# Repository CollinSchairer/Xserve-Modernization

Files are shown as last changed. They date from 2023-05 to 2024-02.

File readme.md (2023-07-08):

Making Apple's beautiful but whacky servers of old useable in 2023.

This project aims to adapt modern ATX computer hardware into the 1U Xserve chassis while maintaining as much of the original design and hardware as possible.
As I work through this project, less and less of this original hardware seems to be useable, but I'm trying my best.

The main components of this modification are a revised front panel I/O and indication board, hard drive caddy modifications, a revised and modernized 
SATA (Maybe SAS?) backplane, and a revised back panel to fit an ATX motherboard I/O cutout and Flex ATX power supply.
# Xserve-Modernization

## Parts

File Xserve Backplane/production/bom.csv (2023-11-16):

Designator | Footprint | Quantity | Value | LCSC Part #
C1 | 0603 | 1 | 10uF
C10 | CP_EIA-7343-15_Kemet-W_Pad2.25x2.55mm_HandSolder | 1 | DNP
C11, C12, C13, C14, C7 | 1210 | 5 | 47uF
C15 | 1210 | 1 | 47 uF
C16, C17 | 0603 | 2 | 10 uF
C2 | 0603 | 1 | 0.1uF
C3 | 0603 | 1 | 2400 pF
C4, C5 | 0603 | 2 | 0.1 uF
C6 | 0603 | 1 | 150 pF
C8 | 0603 | 1 | 22 uF
C9 | CP_EIA-7343-15_Kemet-W_Pad2.25x2.55mm_HandSolder | 1 | 68 uF
CN1, CN2, CN3 | 0678008025_SATA_Conn | 3 | 0678008025_SATA_Conn
D1 | 0805 | 1 | LED_Small
H1 | Slide Mount Hole | 1 | MountingHole_Pad
J1, J7, J8 | 10124274-001TRLF | 3 | ~
J2 | 6_pin_PCI_PWR | 1 | Conn_02x03_Odd_Even
J3 | TE_1888019-2 | 1 | 1888019-2
JP1 | SolderJumper-3_P1.3mm_Bridged2Bar12_Pad1.0x1.5mm_NumberLabels | 1 | Jumper_3_Bridged12
L1 | L_12x12mm_H8mm | 1 | 15 uH
Q1, Q2, Q3, Q4, Q5, Q6 | SOT-23 | 6 | Q_NMOS_DGS
R1 | 0603 | 1 | 19.1 k
R10, R3 | 0603 | 2 | 10k
R2 | 0603 | 1 | 52.3k
R4, R5, R6, R7 | 0603 | 4 | 500 k
R8 | 0603 | 1 | 100 k
R9 | 0603 | 1 | 500 k
TP1 | TheColonelCu | 1 | TestPoint_Probe
U1 | Texas_HTSOP-8-1EP_3.9x4.9mm_P1.27mm_EP2.95x4.9mm_Mask2.4x3.1mm_ThermalVias | 1 | BD9E302EFJ-E2

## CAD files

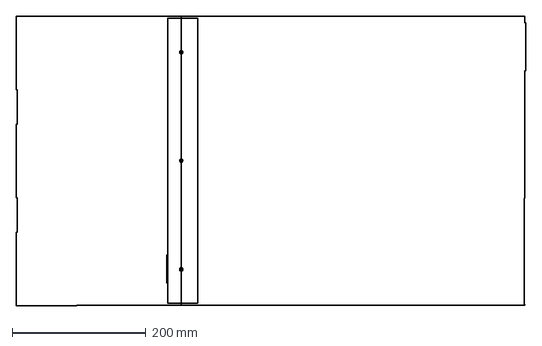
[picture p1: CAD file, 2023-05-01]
Xserve Backplane/backplane_outline.dxf
762.0 x 433.5 mm

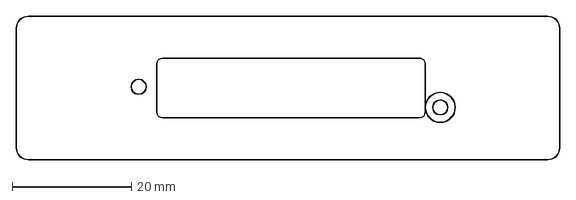
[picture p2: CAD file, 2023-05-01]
Xserve Caddy/Board Outline.dxf
91.0 x 24.0 mm

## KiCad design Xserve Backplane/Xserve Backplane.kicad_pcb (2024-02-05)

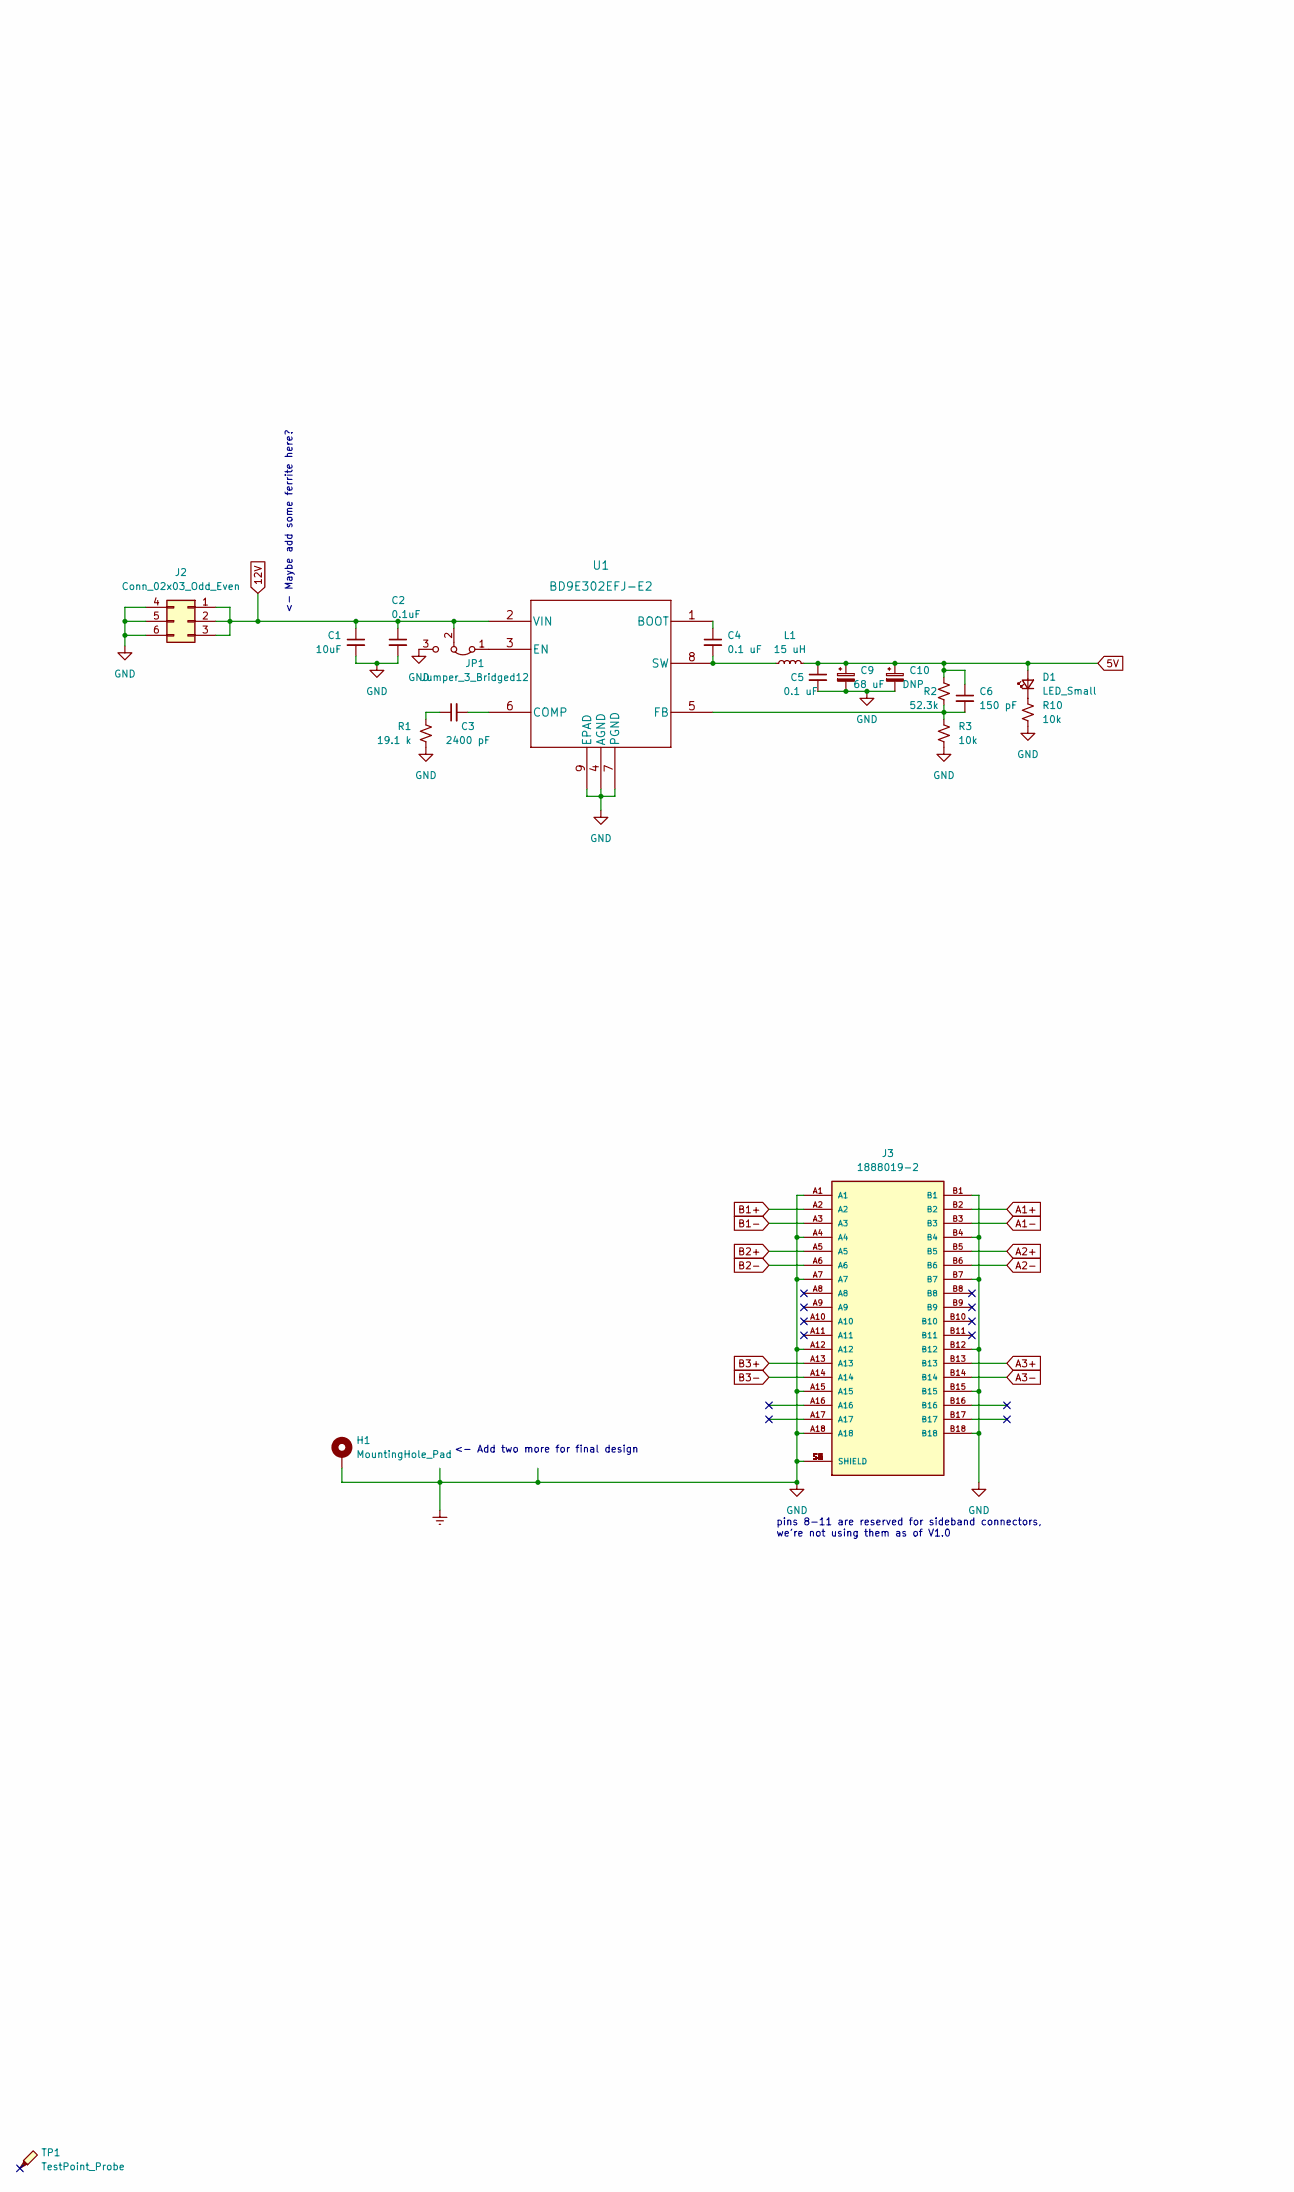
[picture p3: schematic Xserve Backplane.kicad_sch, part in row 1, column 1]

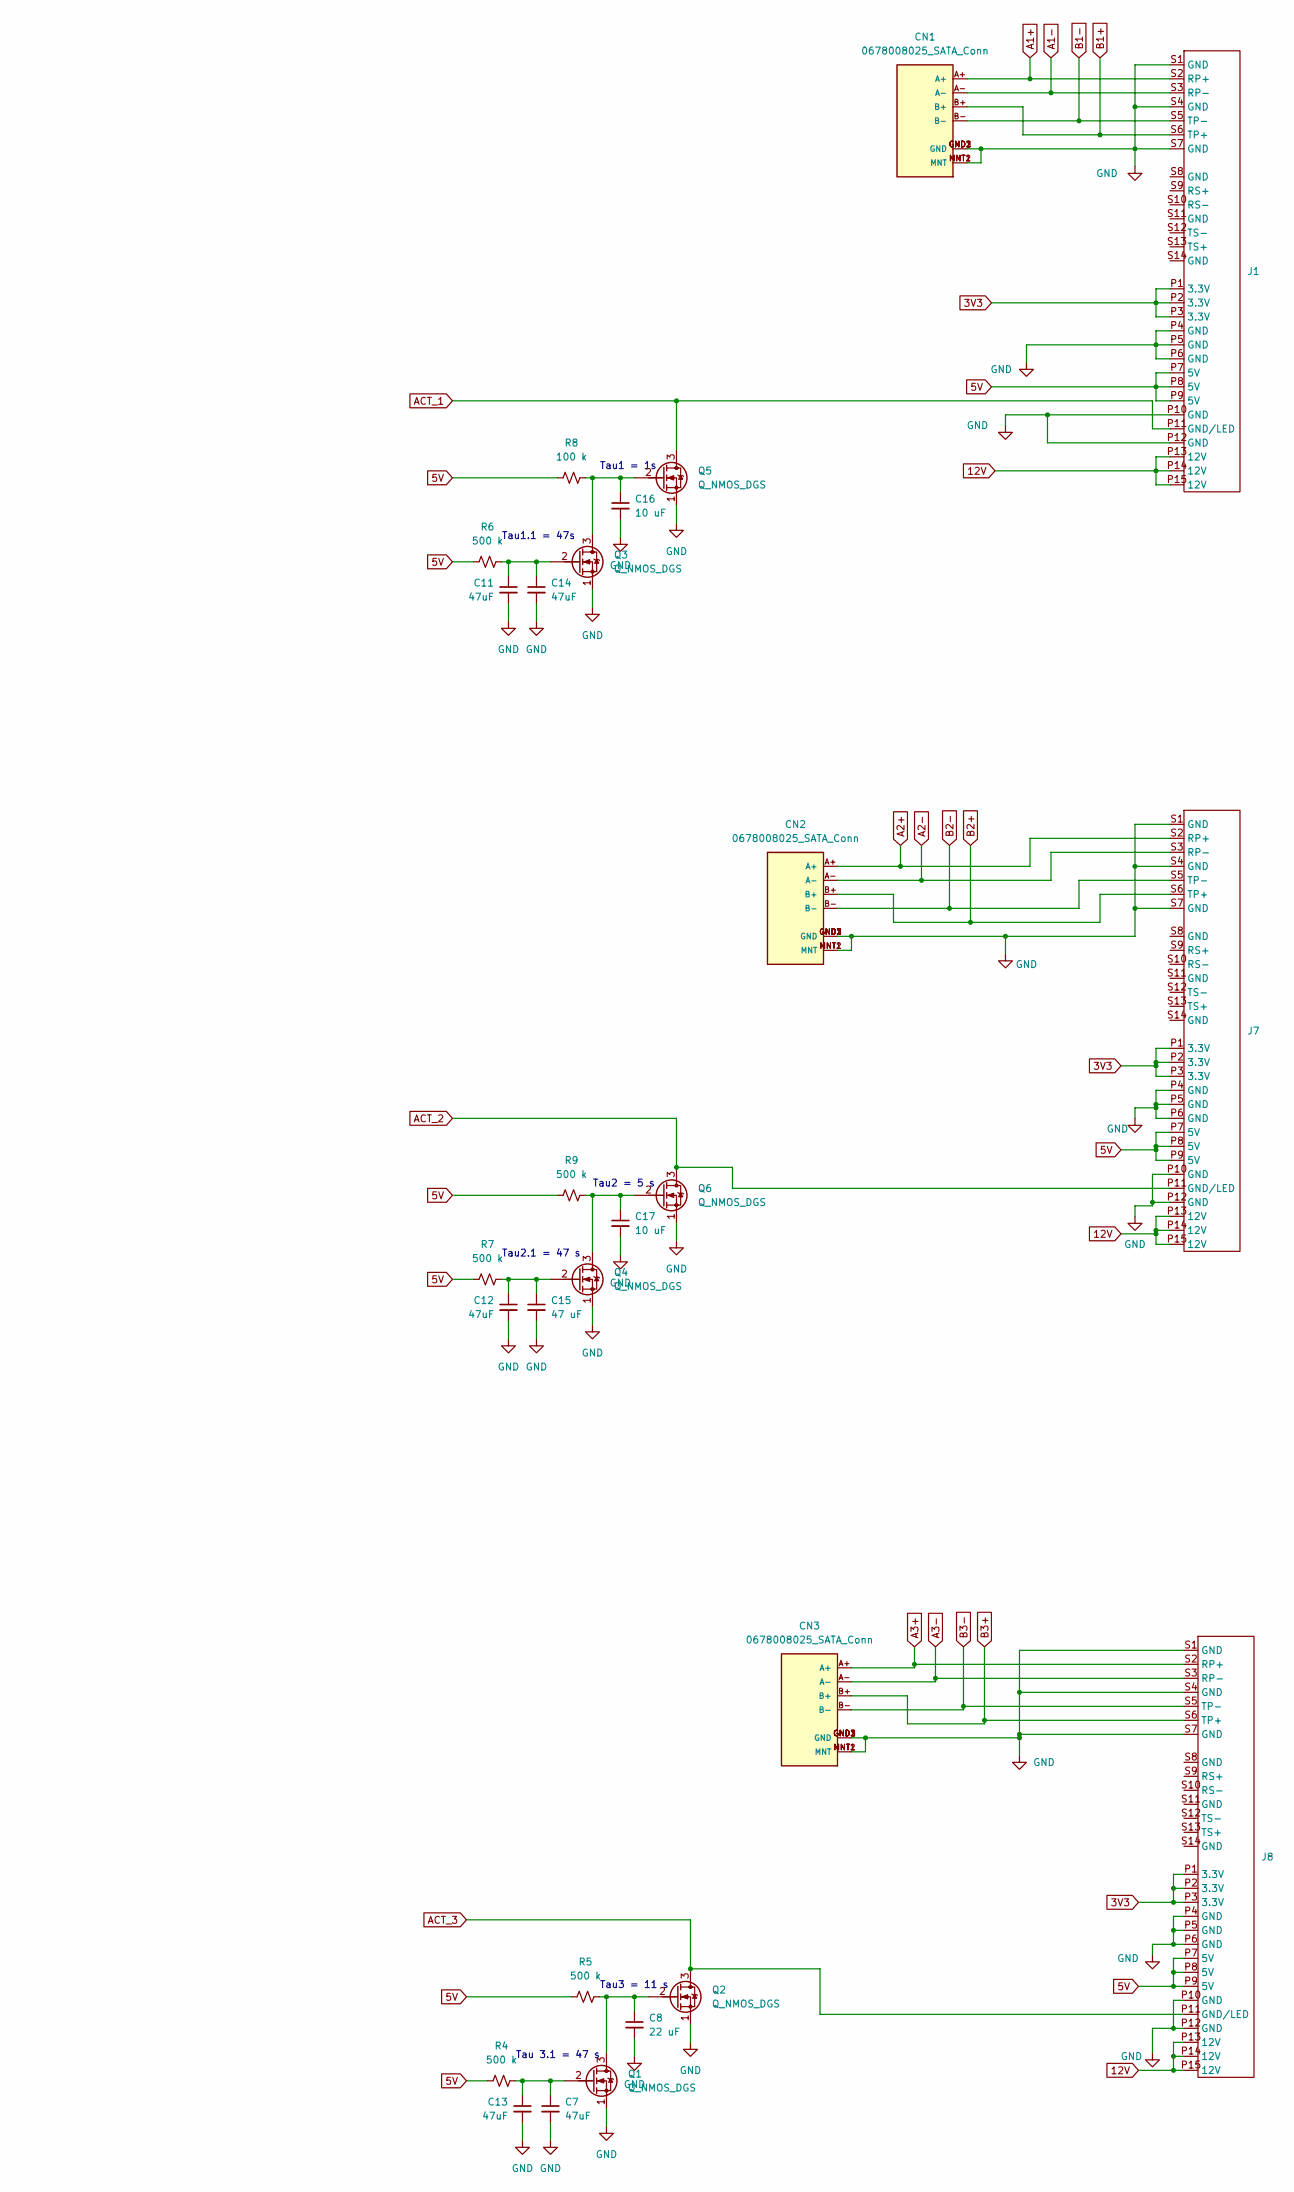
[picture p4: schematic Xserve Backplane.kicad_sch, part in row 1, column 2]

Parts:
C1: 10uF; C_0603_1608Metric_Pad1.08x0.95mm_HandSolder
C2: 0.1uF; C_0603_1608Metric_Pad1.08x0.95mm_HandSolder
C3: 2400 pF; C_0603_1608Metric_Pad1.08x0.95mm_HandSolder
C4, C5: 0.1 uF; C_0603_1608Metric_Pad1.08x0.95mm_HandSolder
C6: 150 pF; C_0603_1608Metric_Pad1.08x0.95mm_HandSolder
C7, C11, C12, C13, C14: 47uF; C_1210_3225Metric_Pad1.33x2.70mm_HandSolder
C8: 22 uF; C_0603_1608Metric_Pad1.08x0.95mm_HandSolder
C9: 68 uF; CP_EIA-7343-15_Kemet-W_Pad2.25x2.55mm_HandSolder
C10: DNP; CP_EIA-7343-15_Kemet-W_Pad2.25x2.55mm_HandSolder
C15: 47 uF; C_1210_3225Metric_Pad1.33x2.70mm_HandSolder
C16, C17: 10 uF; C_0603_1608Metric_Pad1.08x0.95mm_HandSolder
CN1, CN2, CN3: 0678008025_SATA_Conn
D1: LED_Small; LED_0805_2012Metric_Pad1.15x1.40mm_HandSolder
H1: MountingHole_Pad; Slide Mount Hole
J1, J7, J8: 10124274-001TRLF
J2: Conn_02x03_Odd_Even; 6_pin_PCI_PWR
J3: 1888019-2; TE_1888019-2
JP1: Jumper_3_Bridged12; SolderJumper-3_P1.3mm_Bridged2Bar12_Pad1.0x1.5mm_NumberLabe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
L1: 15 uH; L_12x12mm_H8mm
Q1, Q2, Q3, Q4, Q5, Q6: Q_NMOS_DGS; SOT-23
R1: 19.1 k; R_0603_1608Metric_Pad0.98x0.95mm_HandSolder
R2: 52.3k; R_0603_1608Metric_Pad0.98x0.95mm_HandSolder
R3, R10: 10k; R_0603_1608Metric_Pad0.98x0.95mm_HandSolder
R4, R5, R6, R7, R9: 500 k; R_0603_1608Metric_Pad0.98x0.95mm_HandSolder
R8: 100 k; R_0603_1608Metric_Pad0.98x0.95mm_HandSolder
TP1: TestPoint_Probe; TheColonelCu
U1: BD9E302EFJ-E2; Texas_HTSOP-8-1EP_3.9x4.9mm_P1.27mm_EP2.95x4.9mm_Mask2.4x3.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

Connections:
3V3: J1.P1 (3.3V), J1.P2 (3.3V), J1.P3 (3.3V), J7.P1 (3.3V), J7.P2 (3.3V), J7.P3 (3.3V), J8.P1 (3.3V), J8.P2 (3.3V), J8.P3 (3.3V)
5V: C5.1, C6.1, C9.1, C10.1, D1.2 (A), J1.P7 (5V), J1.P8 (5V), J1.P9 (5V), J7.P7 (5V), J7.P8 (5V), J7.P9 (5V), J8.P7 (5V), J8.P8 (5V), J8.P9 (5V), L1.2, R2.1, R4.1, R5.1, R6.1, R7.1, R8.1, R9.1
12V: C1.1, C2.1, J1.P13 (12V), J1.P14 (12V), J1.P15 (12V), J2.1, J2.2, J2.3, J7.P13 (12V), J7.P14 (12V), J7.P15 (12V), J8.P13 (12V), J8.P14 (12V), J8.P15 (12V), JP1.2 (C), U1.2 (VIN)
A1+: CN1.A+, J1.S2 (RP+), J3.B2
A1-: CN1.A-, J1.S3 (RP-), J3.B3
A2+: CN2.A+, J3.B5, J7.S2 (RP+)
A2-: CN2.A-, J3.B6, J7.S3 (RP-)
A3+: CN3.A+, J3.B13, J8.S2 (RP+)
A3-: CN3.A-, J3.B14, J8.S3 (RP-)
ACT_1: J1.P11 (GND/LED), Q5.3 (D)
ACT_2: J7.P11 (GND/LED), Q6.3 (D)
ACT_3: J8.P11 (GND/LED), Q2.3 (D)
B1+: CN1.B+, J1.S6 (TP+), J3.A2
B1-: CN1.B-, J1.S5 (TP-), J3.A3
B2+: CN2.B+, J3.A5, J7.S6 (TP+)
B2-: CN2.B-, J3.A6, J7.S5 (TP-)
B3+: CN3.B+, J3.A13, J8.S6 (TP+)
B3-: CN3.B-, J3.A14, J8.S5 (TP-)
Earth: C1.2, C2.2, C5.2, C7.2, C8.2, C9.2, C10.2, C11.2, C12.2, C13.2, C14.2, C15.2, C16.2, C17.2, CN1.GND1 (GND), CN1.GND2 (GND), CN1.GND3 (GND), CN1.MNT1 (MNT), CN1.MNT2 (MNT), CN2.GND1 (GND), CN2.GND2 (GND), CN2.GND3 (GND), CN2.MNT1 (MNT), CN2.MNT2 (MNT), CN3.GND1 (GND), CN3.GND2 (GND), CN3.GND3 (GND), CN3.MNT1 (MNT), CN3.MNT2 (MNT), H1.1, J1.P4 (GND), J1.P5 (GND), J1.P6 (GND), J1.P10 (GND), J1.P12 (GND), J1.S1 (GND), J1.S4 (GND), J1.S7 (GND), J2.4, J2.5, J2.6, J3.A1, J3.A4, J3.A7, J3.A12, J3.A15, J3.A18, J3.B1, J3.B4, J3.B7, J3.B12, J3.B15, J3.B18, J3.S1 (SHIELD), J3.S2 (SHIELD), J3.S3 (SHIELD), J3.S4 (SHIELD), J3.S5 (SHIELD), J3.S6 (SHIELD), J7.P4 (GND), J7.P5 (GND), J7.P6 (GND), J7.P10 (GND), J7.P12 (GND), J7.S1 (GND), J7.S4 (GND), J7.S7 (GND), J8.P4 (GND), J8.P5 (GND), J8.P6 (GND), J8.P10 (GND), J8.P12 (GND), J8.S1 (GND), J8.S4 (GND), J8.S7 (GND), JP1.3 (B), Q1.1 (S), Q2.1 (S), Q3.1 (S), Q4.1 (S), Q5.1 (S), Q6.1 (S), R1.2, R3.2, R10.2, U1.4 (AGND), U1.7 (PGND), U1.9 (EPAD)
unnamed: C3.1, R1.1
unnamed: D1.1 (K), R10.1
unnamed: JP1.1 (A), U1.3 (EN)
unnamed: C8.1, Q1.3 (D), Q2.2 (G), R5.2
unnamed: C7.1, C13.1, Q1.2 (G), R4.2
unnamed: C16.1, Q3.3 (D), Q5.2 (G), R8.2
unnamed: C11.1, C14.1, Q3.2 (G), R6.2
unnamed: C17.1, Q4.3 (D), Q6.2 (G), R9.2
unnamed: C12.1, C15.1, Q4.2 (G), R7.2
unnamed: C4.1, U1.1 (BOOT)
unnamed: C3.2, U1.6 (COMP)
unnamed: C6.2, R2.2, R3.1, U1.5 (FB)
unnamed: C4.2, L1.1, U1.8 (SW)

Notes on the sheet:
Tau2.1 = 47 s
pins 8-11 are reserved for sideband connectors, we're not using them as of V1.0
<- Add two more for final design
Tau2 = 5 s
<- Maybe add some ferrite here?
Tau1 = 1s
Tau1.1 = 47s
Tau3 = 11 s
Tau 3.1 = 47 s

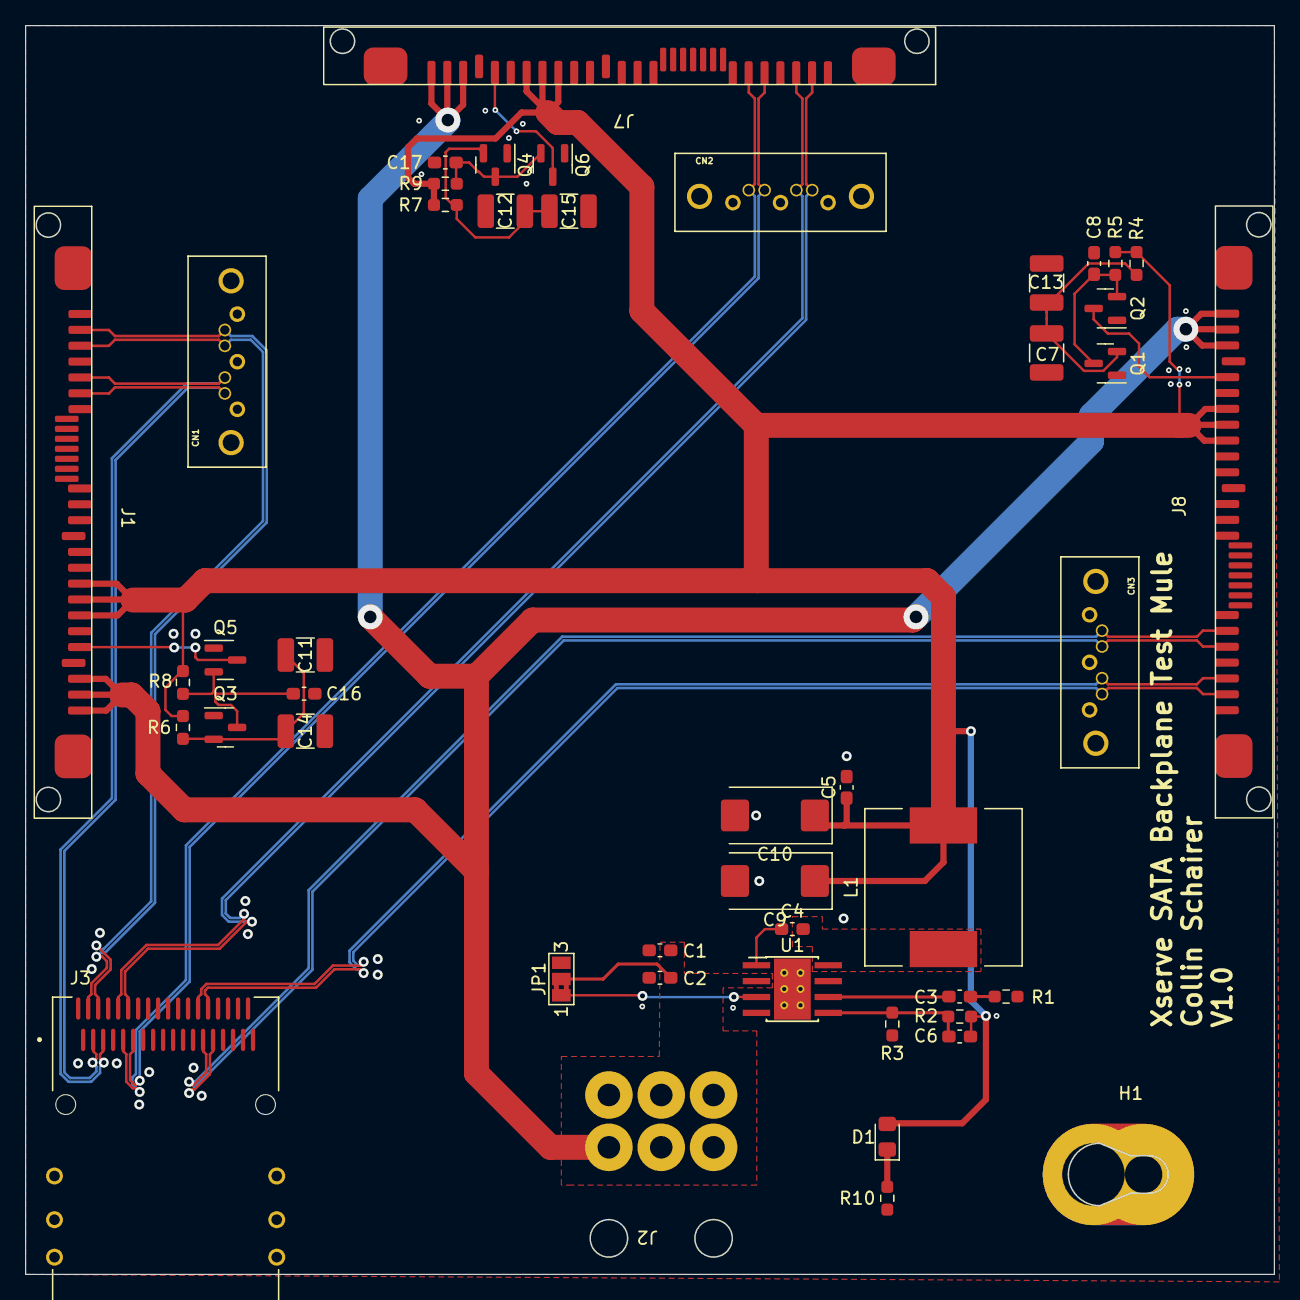
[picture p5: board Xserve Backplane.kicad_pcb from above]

Board: 4 copper layers, 100.0 x 100.0 mm, 47 parts (0 on the bottom side), 32 nets.

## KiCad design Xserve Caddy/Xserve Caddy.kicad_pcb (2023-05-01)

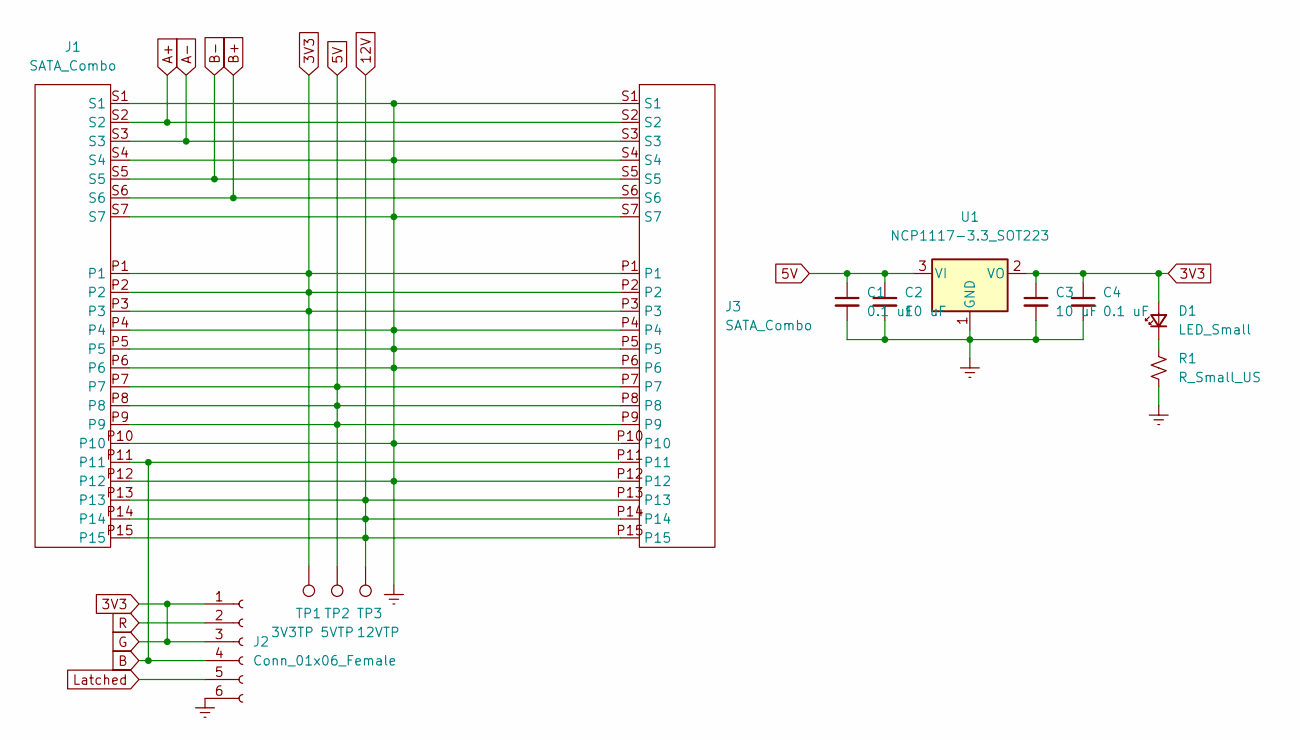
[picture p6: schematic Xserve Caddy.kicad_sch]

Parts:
C1, C4: 0.1 uF; C_0603_1608Metric_Pad1.08x0.95mm_HandSolder
C2, C3: 10 uF; C_0603_1608Metric_Pad1.08x0.95mm_HandSolder
D1: LED_Small; LED_0805_2012Metric_Pad1.15x1.40mm_HandSolder
J1, J3: SATA_Combo; 5622-2103-ML
J2: Conn_01x06_Female; Molex_PicoBlade_53048-0610_1x06_P1.25mm_Horizontal
R1: R_Small_US; R_0603_1608Metric_Pad0.98x0.95mm_HandSolder
TP1: 3V3TP; TestPoint_Pad_D2.0mm
TP2: 5VTP; TestPoint_Pad_D2.0mm
TP3: 12VTP; TestPoint_Pad_D2.0mm
U1: NCP1117-3.3_SOT223; SOT-223-3_TabPin2

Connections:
3V3: C3.1, C4.1, D1.2 (A), J1.P1, J1.P2, J1.P3, J2.1, J2.3, J3.P1, J3.P2, J3.P3, TP1.1, U1.2 (VO)
5V: C1.1, C2.1, J1.P7, J1.P8, J1.P9, J3.P7, J3.P8, J3.P9, TP2.1, U1.3 (VI)
12V: J1.P13, J1.P14, J1.P15, J3.P13, J3.P14, J3.P15, TP3.1
A+: J1.S2, J3.S2
A-: J1.S3, J3.S3
B: J1.P11, J2.4, J3.P11
B+: J1.S6, J3.S6
B-: J1.S5, J3.S5
Earth: C1.2, C2.2, C3.2, C4.2, J1.P4, J1.P5, J1.P6, J1.P10, J1.P12, J1.S1, J1.S4, J1.S7, J2.6, J3.P4, J3.P5, J3.P6, J3.P10, J3.P12, J3.S1, J3.S4, J3.S7, R1.2, U1.1 (GND)
Latched: J2.5
unnamed: D1.1 (K), R1.1
R: J2.2

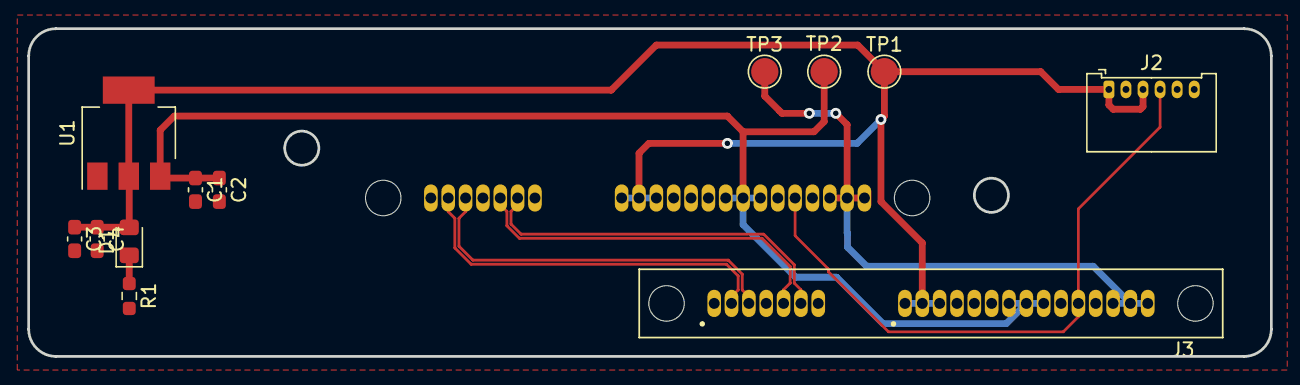
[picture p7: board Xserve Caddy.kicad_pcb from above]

Board: 4 copper layers, 91.0 x 24.0 mm, 13 parts (1 on the bottom side), 10 nets.

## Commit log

2023-05-01 init of project on github
    [Board Outline.dxf, Xserve Backplane.kicad_pcb, Xserve Backplane.kicad_sch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]
2023-05-01 init project on github
    [Board Outline.dxf, Xserve Backplane.kicad_pcb, Xserve Backplane.kicad_sch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]
2023-05-26 "Ran DRC, changed mosfet footprint"
    [Board Outline.dxf, Xserve Backplane.kicad_pcb, Xserve Backplane.kicad_sch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]
2023-06-15 small updates
    [Board Outline.dxf, Xserve Backplane.kicad_pcb, Xserve Backplane.kicad_sch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]
2023-07-08 Creatd Ampehnol SAS connector footprint and implemented in schematic. Began implementation in layout.
    [Xserve Backplane.kicad_pcb, Xserve Backplane.kicad_sch, Xserve Front Panel.kicad_pcb]
2023-07-30 created SAS connector footprint and added to layout. next step is routing with new connector
    [Xserve Backplane.kicad_pcb, Xserve Backplane.kicad_sch]
2023-07-31 rough pass at SAS connector layout and some DRC fixes, this board should be manufacturable.
    [Xserve Backplane.kicad_pcb, Xserve Backplane.kicad_sch]
2023-11-16 misinterpreted JLC's via size capabilities. increased minimum via to 0.46 mm to comply with their requirements.
    [Xserve Backplane.kicad_pcb, Xserve Backplane.kicad_sch, Xserve Front Panel.kicad_sch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]
2023-11-28 got the front panel PCB schematic to a decent place. Just need to fill in the details (all the passive values, maybe add some fuses, clean up the schematic).
    [Xserve Front Panel.kicad_sch]
2024-02-05 Incremental changes, not exactly sure what's in this commit but thought it best to commit.
    [Xserve Backplane.kicad_pcb, Xserve Front Panel.kicad_sch]
